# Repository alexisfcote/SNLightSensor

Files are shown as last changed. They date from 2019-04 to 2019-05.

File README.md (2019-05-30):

# SNLightSensor
Author: Alexis Fortin-Côté (2019)

Arduino project using Adafruit Adalogger 32u4, adafruit RTC featherwing and Sparkfun Spectral Sensor Breakout to log sensor to SD card with accurate timestamp.

The shipped libraries (libraries.zip) need to be installed in the Arduino IDE to compile.

The LightSensor folder contains the program main arduino program for the Microcontroller.
The "file transfer tool" folder contains a tool for usb transfer of files. A windows executable can be created with pyinstaller.

The microcontroller makes a reading of the sensor, time from the RTC and battery voltage every 8sec and writes to the sd card after 8 readings to save on battery. The microcontroller put itself into deep spleep between readings.

The RTC should be accurate to ±5sec per year. The coin battery used for back up power to the RTC should last for 7 years.

The 500mAh LiPo battery can last 1 day and 16 hours. The 2000mAh LiPo battery should therefore last 6 days and 18 hours.

1 week of recordings amounts to about 1MB of data. The 32GB sd card should therefore provide virtually limitless record space.

On power on the board checks if everything is in place. If something is missing (RTC, SD card or Spectral sensor) it rapidly blink indefinitely. Check the connection and restart the board by removing LiPo battery and usb power. The board will send initialization messages on the serial port (9600 baud) at boot. This can be used for diagnostic. When running normally (after the ~30 sec boot period) the LED will double blink at interval of 8 sec.

By programming the board with the AS7262 program (in the AS7262 folder), the spectral_monitor.py app can be used to make continuous reading and display of the sensor.

The board is made of those parts:
Adafruit Feather 32u4 Adalogger
DS3231 Precision RTC Featherwing
Sparkfun Qwiic Adapter (soldered on the RTC Featherwing)
Sparkfun Spectral Sensor Borad AS7262 Visible

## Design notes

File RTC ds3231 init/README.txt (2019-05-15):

Code to initialise the RTC clock.
Upload to the Adalogger connected to the RTC 1 time.
The clock will keep time for 7 years with the coin cell battery

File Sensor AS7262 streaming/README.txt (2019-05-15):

Program to visualize spectral readings from AS7262 sensor plugged to the adalogger programmed with AS7262.ino

compile:
pyinstaller spectral_monitor.py -F -w

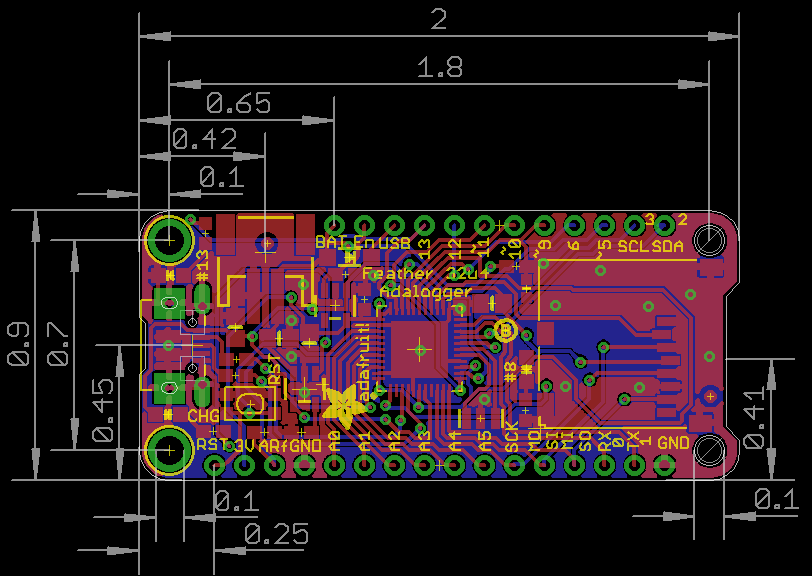
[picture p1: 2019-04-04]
CAD/adafruit_products_fabprint.png

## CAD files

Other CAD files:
CAD/Enclosure v6.f3d

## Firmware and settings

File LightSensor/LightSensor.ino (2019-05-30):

// Date and time functions using a DS3231 RTC connected via I2C and Wire lib
#include <Wire.h>
#include <avr/power.h>
#include "RTClib.h"
#include <SPI.h>
#include <SD.h>
#include "LowPower.h"
#include "AS726X.h"

#define VBATPIN A9
#define LOWPOWER; // Disable serial print

// reat time clock
RTC_DS3231 rtc;
char daysOfTheWeek[7][12] = {"Sunday", "Monday", "Tuesday", "Wednesday", "Thursday", "Friday", "Saturday"};

// Light sensor
AS726X sensor;

// SD card
const int chipSelect = 4;
int i = 0;
unsigned long last_file_size = 0;
String fileName;
File dataFile;

void error() {
  while (1) {
    pinMode (LED_BUILTIN, OUTPUT);
    digitalWrite (LED_BUILTIN, HIGH);
    delay (100);
    digitalWrite (LED_BUILTIN, LOW);
    delay (100);
  }
}

DateTime get_now() {
  power_twi_enable();
  DateTime now = rtc.now();
  power_twi_disable();
  return now;
}

void print_time() {
  DateTime now = get_now();
  Serial.begin(9600);
  while (!Serial) { }  // wait for Serial to initialize
  Serial.print(now.year(), DEC);
  Serial.print('/');
  Serial.print(now.month(), DEC);
  Serial.print('/');
  Serial.print(now.day(), DEC);
  Serial.print(" (");
  Serial.print(daysOfTheWeek[now.dayOfTheWeek()]);
  Serial.print(") ");
  Serial.print(now.hour(), DEC);
  Serial.print(':');
  Serial.print(now.minute(), DEC);
  Serial.print(':');
  Serial.print(now.second(), DEC);
  Serial.println();
  Serial.flush();
  Serial.end();
}

void flash() {
  pinMode (LED_BUILTIN, OUTPUT);
  digitalWrite (LED_BUILTIN, HIGH);
  delay (50);
  digitalWrite (LED_BUILTIN, LOW);
  delay (50);
  digitalWrite (LED_BUILTIN, HIGH);
  delay (50);
  digitalWrite (LED_BUILTIN, LOW);
  pinMode (LED_BUILTIN, INPUT);
}

String gatherMeasurements() {
  power_twi_enable();
  if (!sensor.isalive()) error();
  String measurements = "";
  sensor.takeMeasurements();
  byte tempC = sensor.getTemperature();
  measurements += String(tempC);
  measurements += ",";
  measurements += String(sensor.getCalibratedViolet());
  measurements += ",";
  measurements += String(sensor.getCalibratedBlue());
  measurements += ",";
  measurements += String(sensor.getCalibratedGreen());
  measurements += ",";
  measurements += String(sensor.getCalibratedYellow());
  measurements += ",";
  measurements += String(sensor.getCalibratedOrange());
  measurements += ",";
  measurements += String(sensor.getCalibratedRed());
  power_twi_disable();
  return measurements;
}

void prepare_SD_file() {
  Serial.println("Open File...");
  DateTime now = get_now();
  fileName = "";
  fileName += String(now.year());
  char buff[4];
  sprintf(buff, "%02d", now.month());
  fileName += String(buff);
  sprintf(buff, "%02d", now.day());
  fileName += String(buff);
  fileName += ".txt";
  File dataFile = SD.open(fileName, FILE_WRITE);

  if (!dataFile) {
    Serial.print("error opening ");
    Serial.println(fileName);
    error();
  }
  last_file_size =  dataFile.size();

  Serial.print(fileName);
  Serial.println(" Prepared");

  dataFile.println("UnixTime, VBat, T°C, V, B, G, Y, O, R");
  dataFile.close();
  dataFile = SD.open(fileName, FILE_WRITE);
}

void write_to_SD() {
  String dataString = String(get_now().unixtime());
  dataString += ",";

  // Bat voltage
  power_adc_enable();
  ADCSRA |= 1 << 7;
  float measuredvbat = analogRead(VBATPIN);
  ADCSRA = 0;
  power_adc_disable();
  measuredvbat *= 2;    // we divided by 2, so multiply back
  measuredvbat *= 3.3;  // Multiply by 3.3V, our reference voltage
  measuredvbat /= 1024; // convert to voltage
  dataString += String(measuredvbat);
  dataString += ",";

  // Light sensor
  dataString += gatherMeasurements();

  // SD card write
  power_spi_enable();
  dataFile.println(dataString);
#ifndef LOWPOWER
  Serial.println(dataString);
#endif
  if (i >= 8) {
    dataFile.flush();
    dataFile.close();
    dataFile = SD.open(fileName, FILE_WRITE);
    if (!dataFile) error();
    unsigned long file_size =  dataFile.size();
    if (file_size <= last_file_size) error();
    last_file_size = file_size;
    i = 0;
  }
  i++;
  power_spi_disable();
}

void power_all() {
  power_adc_enable(); // ADC converter
  power_spi_enable(); // SPI
  power_usart0_enable(); // Serial (USART)
  power_timer0_enable(); // Timer 0
  power_timer1_enable(); // Timer 1
  power_timer2_enable(); // Timer 2
  power_twi_enable(); // TWI (I2C)
}

void power_down() {
  // Disable USB clock
  USBCON |= _BV(FRZCLK);
  // Disable USB PLL
  PLLCSR &= ~_BV(PLLE);
  // Disable USB
  USBCON &= ~_BV(USBE);

  // disable ADC
  ADCSRA = 0;

  power_adc_disable(); // ADC converter
  power_twi_disable(); // TWI (I2C)
  power_spi_disable(); // SPI
  //power_timer0_disable();// Timer 0
  power_timer1_disable();// Timer 1
  power_timer2_disable();// Timer 2

#ifdef LOWPOWER
  power_usart0_disable();// Serial (USART)
  Serial.end();
#endif
}

void printDirectory(File dir) {
  while (true) {
    File entry =  dir.openNextFile();
    if (! entry) {
      // no more files
      break;
    }
    if (!entry.isDirectory()) {
      Serial.print(entry.name());
      Serial.print("\t\t");
      Serial.println(entry.size(), DEC);
    }
    entry.close();
  }
}

void upload_files() {
  File root = SD.open("/");
  printDirectory(root);
  root.close();
  
  while (true) {
    Serial.println("Waiting for choice");
    delay(500);
    if (Serial.available() > 0) {
      String filetoopen = Serial.readString();
      // Length (with one extra character for the null terminator)
      int str_len = filetoopen.length() + 1; 
      // Prepare the character array (the buffer) 
      char char_array[str_len];
      
      // Copy it over 
      filetoopen.toCharArray(char_array, str_len);
      File dataFile = SD.open(char_array);
      Serial.println("Received file to open");
      Serial.println(filetoopen);

      // if the file is available, write to it:
      if (dataFile) {
        Serial.println("Prepare Sending File");
        while (dataFile.available()) {
          Serial.write(dataFile.read());
        }
        Serial.println("Done");
        dataFile.close();
      }
      // if the file isn't open, pop up an error:
      else {
        Serial.println("error opening " + filetoopen );
      }
    }
  }

}

void setup() {
  power_all();
  USBDevice.attach();
  delay(1000);

  Serial.begin(9600);
  delay(500);
  Serial.println("Starting");

  Serial.println("Initializing SD card...");
  delay(100);

  // see if the card is present and can be initialized:
  if (!SD.begin(chipSelect)) {
    Serial.println("Card failed, or not present");
    error();
  }
  Serial.println("card initialized.");

  // Check for pc connection to upload files
  bool pc_connected = 0;
  for (uint8_t i = 0; i <= 10; i++) {
    Serial.println("Waiting for PC...");
    if (Serial.available() > 0) {
      Serial.println("PC Connected");
      Serial.read();
      pc_connected = 1;
      break;
    }
    delay(1000);
  }
  if (pc_connected) upload_files();

  Serial.println("No PC Connected");

  prepare_SD_file();

  Serial.println("Initializing spectral sensor...");
  delay(100);
  power_twi_enable();
  if (!sensor.isalive()) error();
  if (sensor.begin(Wire, 3, 3) == 0) error();

  Serial.println("Initializing RTC...");
  delay(100);
  if (! rtc.begin()) {
    Serial.println("Couldn't find RTC");
    error();
  }

  if (rtc.lostPower()) {
    Serial.println("RTC lost power!");
    error();
  }
      
  Serial.println("Going into low power mode");
  delay(100);
  // Power Saving
  power_down();
}

void loop() {
  flash();
  write_to_SD();
#ifdef LOWPOWER
  LowPower.powerDown(SLEEP_8S, ADC_OFF, BOD_OFF);
#else
  delay(1000);
#endif
}

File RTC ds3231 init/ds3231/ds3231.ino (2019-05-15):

// Date and time functions using a DS3231 RTC connected via I2C and Wire lib
#include <Wire.h>
#include "RTClib.h"

RTC_DS3231 rtc;

char daysOfTheWeek[7][12] = {"Sunday", "Monday", "Tuesday", "Wednesday", "Thursday", "Friday", "Saturday"};

void setup () {

  Serial.begin(9600);

  delay(3000); // wait for console opening

  if (! rtc.begin()) {
    Serial.println("Couldn't find RTC");
    while (1);
  }

  if (rtc.lostPower()) {
    Serial.println("RTC lost power, lets set the time!");
    // following line sets the RTC to the date & time this sketch was compiled
    rtc.adjust(DateTime(F(__DATE__), F(__TIME__)) + TimeSpan(17));
    // This line sets the RTC with an explicit date & time, for example to set
    // January 21, 2014 at 3am you would call:
    // rtc.adjust(DateTime(2014, 1, 21, 3, 0, 0));
  }
}

void loop () {
    DateTime now = rtc.now();
    
    Serial.print(now.year(), DEC);
    Serial.print('/');
    Serial.print(now.month(), DEC);
    Serial.print('/');
    Serial.print(now.day(), DEC);
    Serial.print(" (");
    Serial.print(daysOfTheWeek[now.dayOfTheWeek()]);
    Serial.print(") ");
    Serial.print(now.hour(), DEC);
    Serial.print(':');
    Serial.print(now.minute(), DEC);
    Serial.print(':');
    Serial.print(now.second(), DEC);

    Serial.println();
    delay(1000);
}

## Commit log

2019-04-04 Added case CAD
    [Enclosure v1.f3d]
2019-05-10 Update CAD and Analysis
    [Enclosure v1.f3d, Enclosure v6.f3d]
2019-05-15 created spectral monitor exe and updated file transfert so that the sensor and rtc don't need to be plugged in
2019-05-30 Fix no start when no usb
    [LightSensor.ino]
